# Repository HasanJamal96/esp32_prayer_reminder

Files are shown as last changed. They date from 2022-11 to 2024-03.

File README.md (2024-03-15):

# esp32_prayer_reminder
This project is a prayer reminder system built using an ESP32. It assists users in staying informed about prayer times and offers a convenient way to play surahs.

## Hardware
  - ESP32
  - MAX98357
  - 2 push button
  - 1 toggle switch
  - RTC DS3231
  - Speaker

## Working:
### Mode:
  - **Configuration Mode:**
      1. Users connect to a dedicated ESP32 access point and configure settings through a captive portal.
      2. Set RTC time and date for accurate prayer calculations.
      3. Select the user's country for relevant prayer time data.
      4. Connect ESP32 rto Wi-Fi and download prayer timings from the internet.
  - **Normal Mode:**
      1. Provides immediate access to prayer information and surah playback.
      2. Announce the current prayer time upon pressing the first push button.
      3. Play a stored surah from memory by pressing the second push button.

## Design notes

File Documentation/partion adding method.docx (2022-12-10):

Find boards.txt file

Mine is located at

C:\Users\PC\AppData\Local\Arduino15\packages\esp32\hardware\esp32\1.0.6

PC is the name of my computer.
AppData folder is hidden by default, so you have to unhide this.
1.0.6 is the version of ESP32 I am using

Open boards.txt file in text editor and find the following lines.

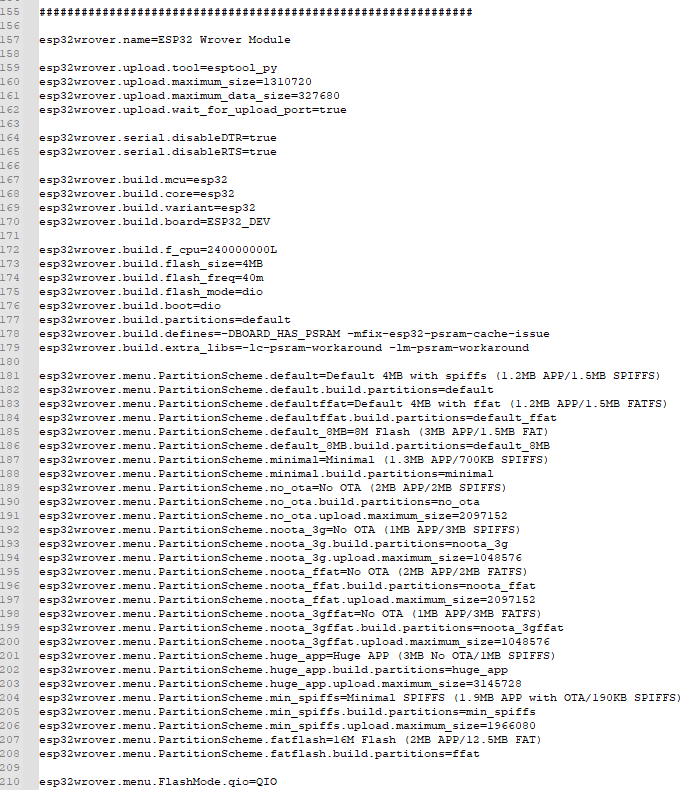
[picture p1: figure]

Add these three lines at the end

esp32wrover.menu.PartitionScheme.large_spiffs=Prayer Partition (1.25MB APP/OTA/12.5MB SPIFFS)
esp32wrover.menu.PartitionScheme.large_spiffs.build.partitions=prayer_partition
esp32wrover.menu.PartitionScheme.large_spiffs.upload.maximum_size=13107200

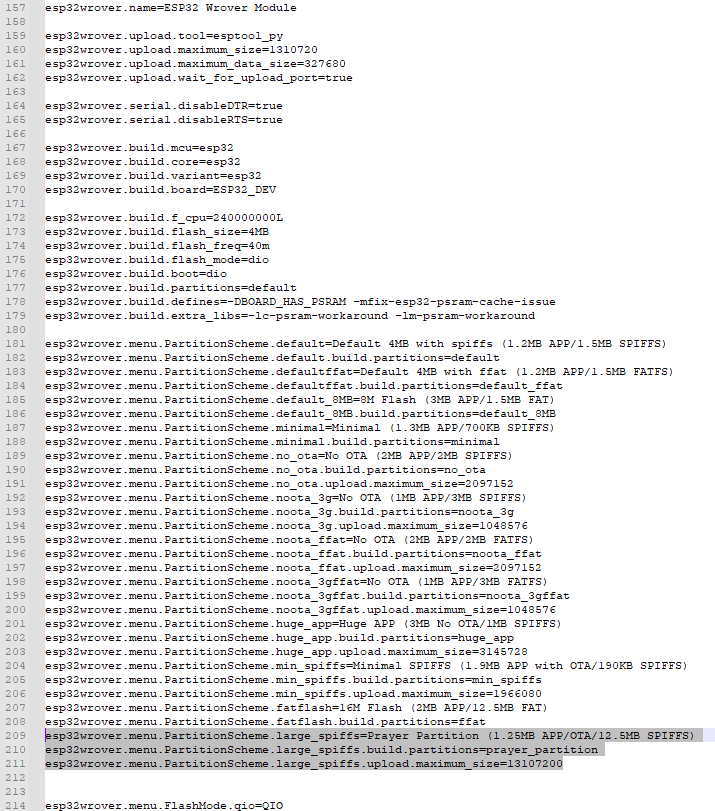
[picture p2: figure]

now go to this location and add this file prayer_partition.csv

C:\Users\PC\AppData\Local\Arduino15\packages\esp32\hardware\esp32\1.0.6\tools\partitions

Before adding

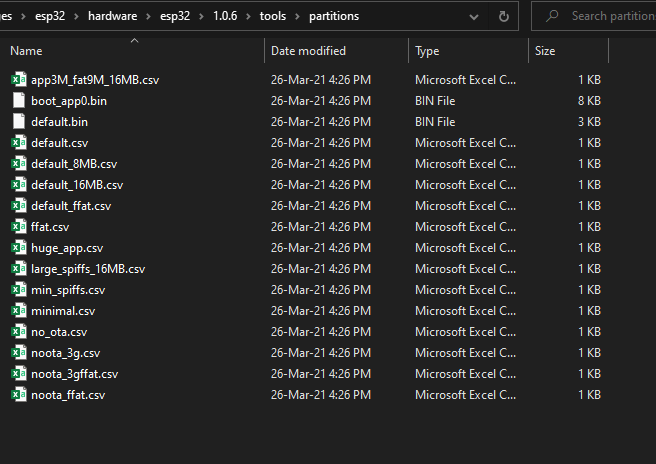
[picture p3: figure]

After adding

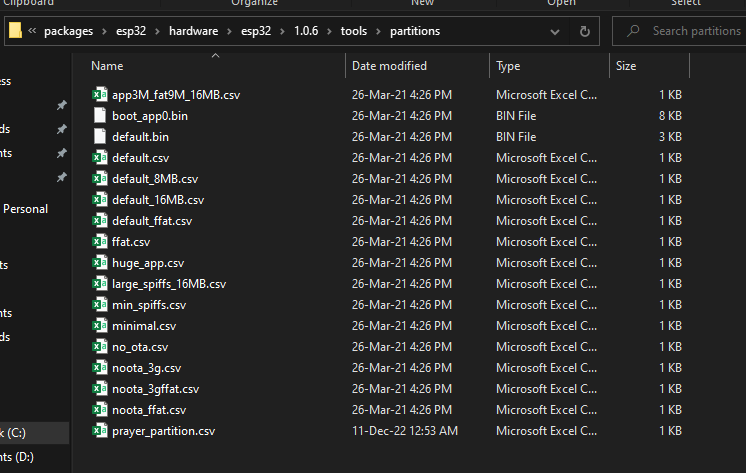
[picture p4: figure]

Restart Arduino IDE, connect ESP32 board

Now select board and partition in IDE under tools

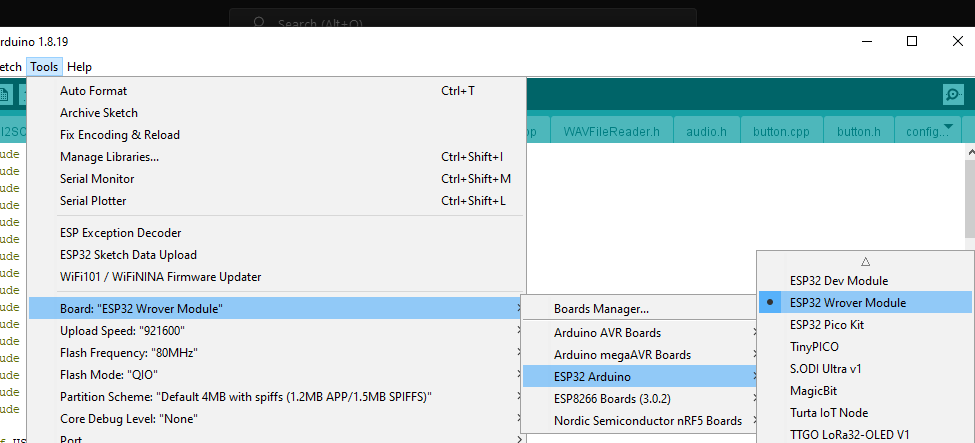
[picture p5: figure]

Select new added partition

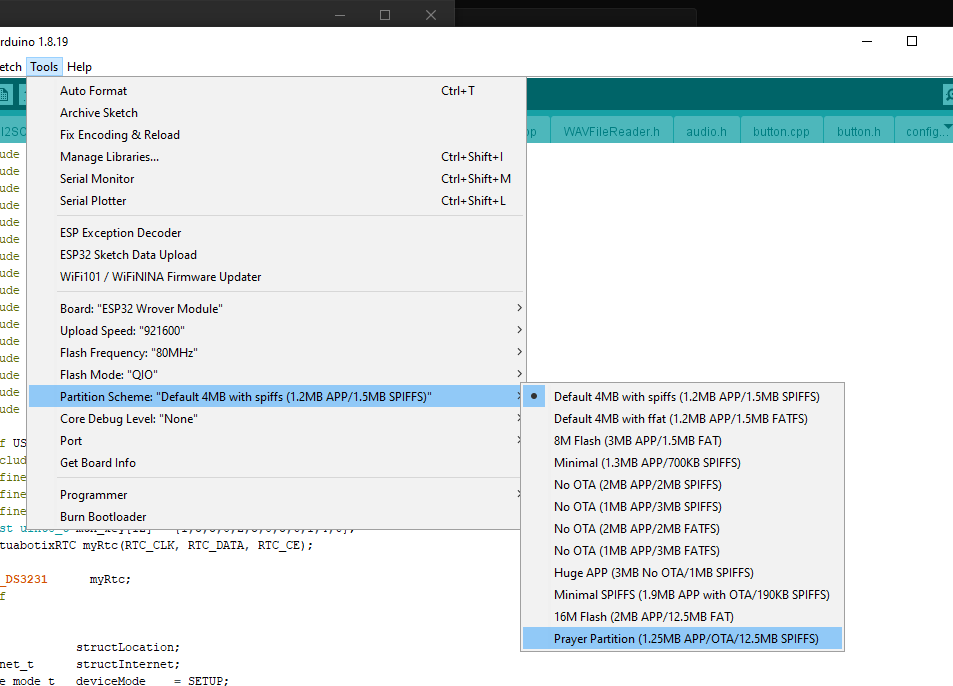
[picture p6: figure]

Upload audio and web files in ESP32

Make sure Serial monitor is close now click on ESP32 Sketch Data Upload.

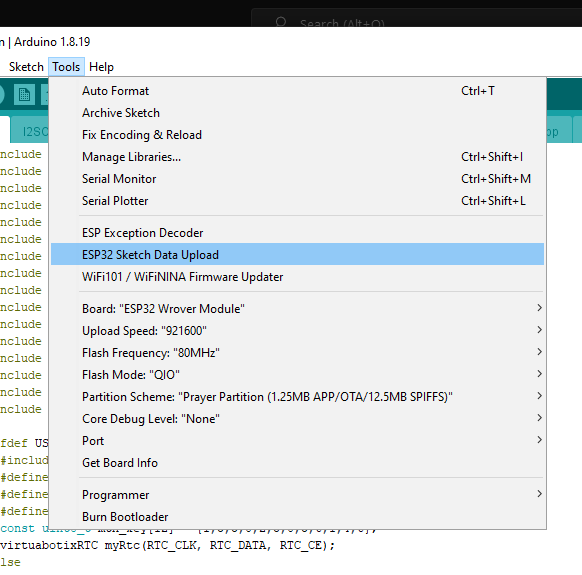
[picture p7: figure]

After successfully upload files in ESP32 now upload code in ESP32.

Click on upload button.

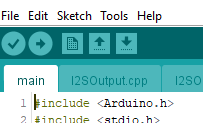
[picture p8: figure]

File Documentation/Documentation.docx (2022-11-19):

Prayer Reminder

Install Arduino IDE:

Download IDE from this link make sure to download version 1.8.19

https://www.arduino.cc/en/software

after downloading follow the installation process.

Add ESP board in Arduino IDE:

1. In Arduino IDE, go to File> Preferences

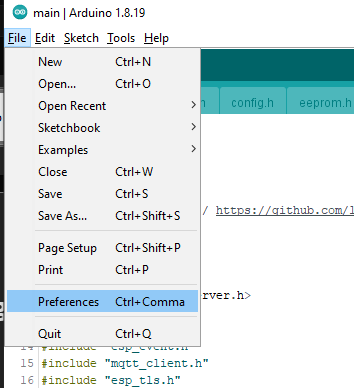
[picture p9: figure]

2. Enter the following into the Additional Board Manager URLs field and click Ok:

https://raw.githubusercontent.com/espressif/arduino-esp32/gh-pages/package_esp32_index.json

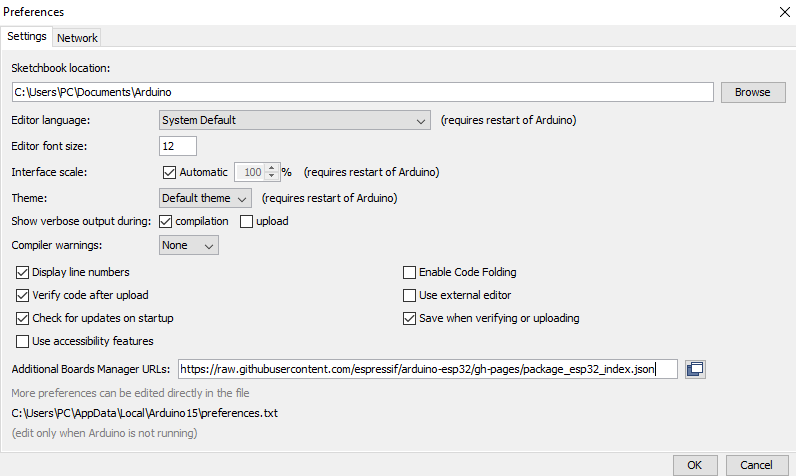
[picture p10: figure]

3. Open the Boards Manager. Go to Tools > Board > Boards Manager…

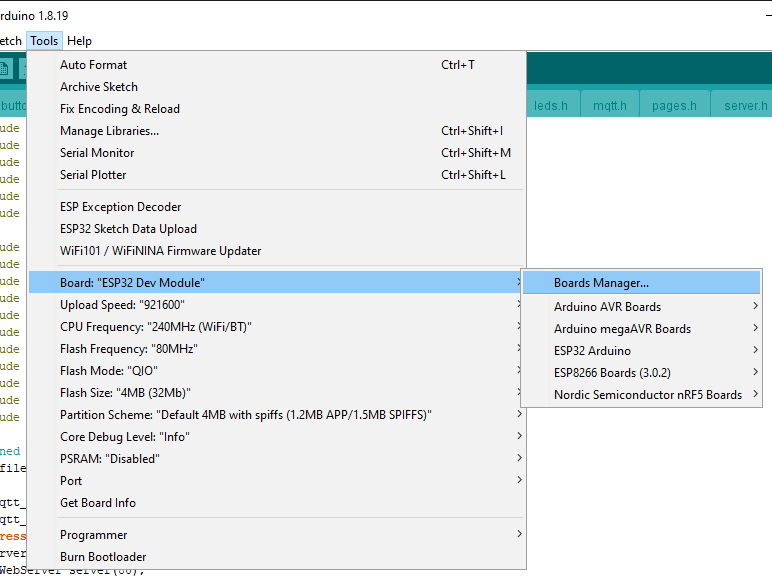
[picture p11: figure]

4. Search for ESP32, select 1.0.6 version and click install

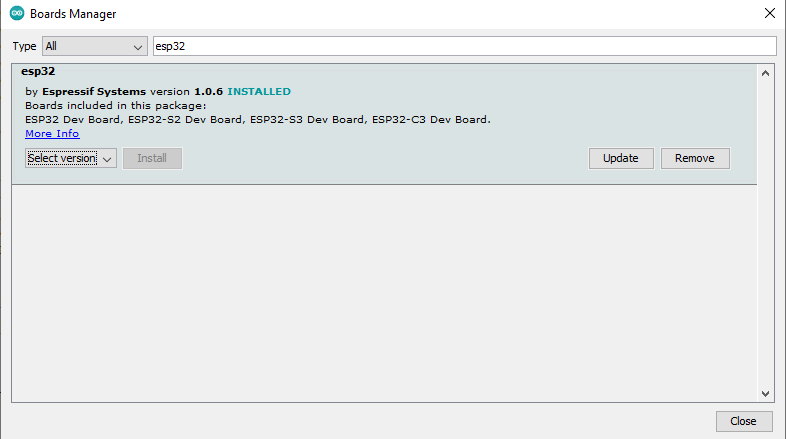
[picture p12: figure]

Install Required Libraries:

All the required libraries added with documentation have to be added in Arduino IDE.

Go to Sketch >> Include Library >> Add .ZIP Library…

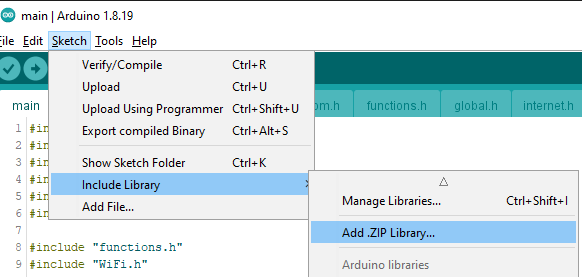
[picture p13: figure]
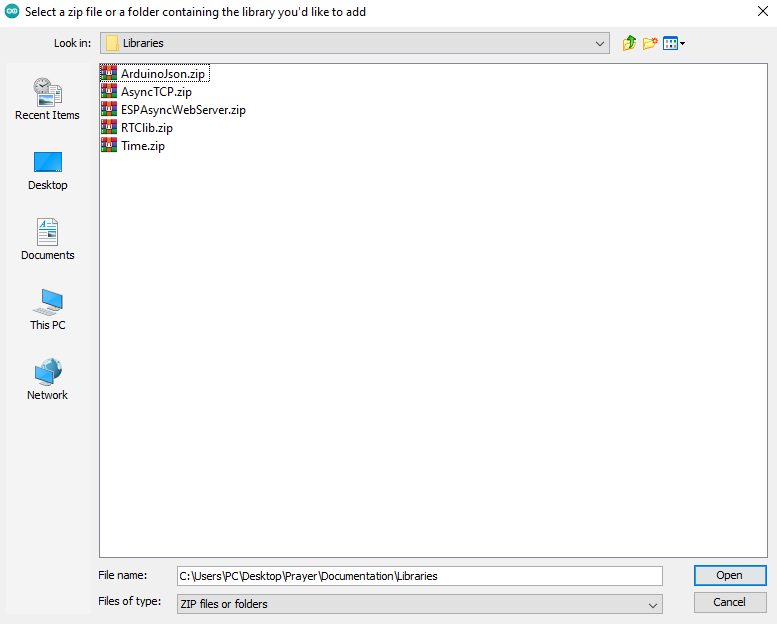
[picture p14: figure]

To the Libraries added with this documentation and select any one of the libraries.

Follow the same for others.

In config.h file you can enable/disable debugging of the code.

Uncomment these lines to enable debugging.

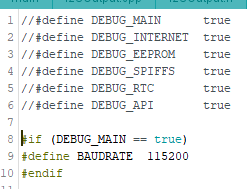
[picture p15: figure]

Debugging will be shown on Serial Monitor. Make sure in final version comment these lines to save memory and processing power of the controller.

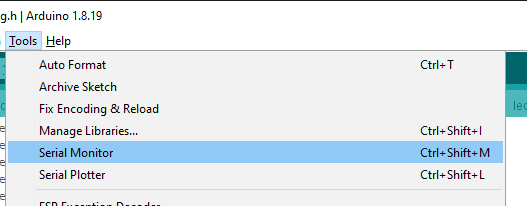
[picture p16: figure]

How to upload code in Controller

Connect controller with PC.

Select following settings in IDE.

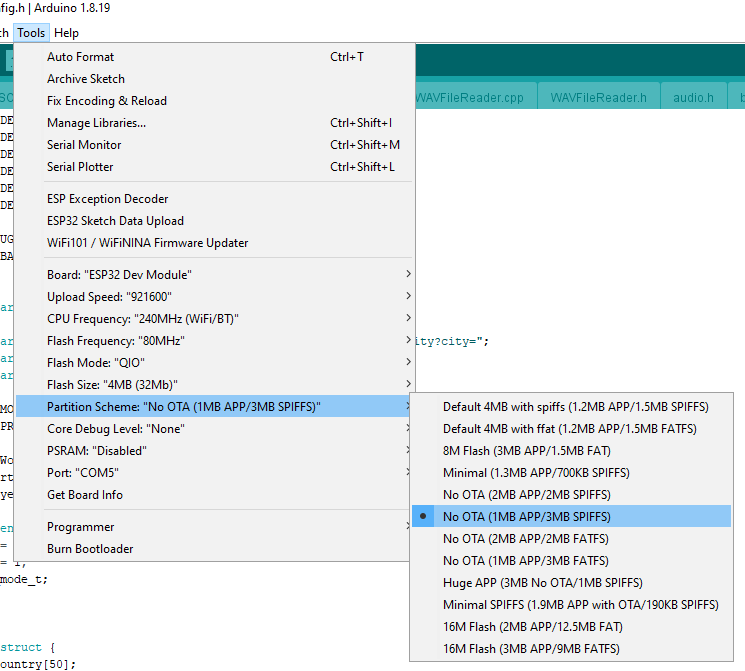
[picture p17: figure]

Port will be the COM port at which your ESP Controller is connected.

Click on upload button and code should upload in the controller after compiling.

How to upload files (Audio/Setup) in ESP Memory

1. Go to the following link and download the highlighted file

https://github.com/me-no-dev/arduino-esp32fs-plugin/releases/

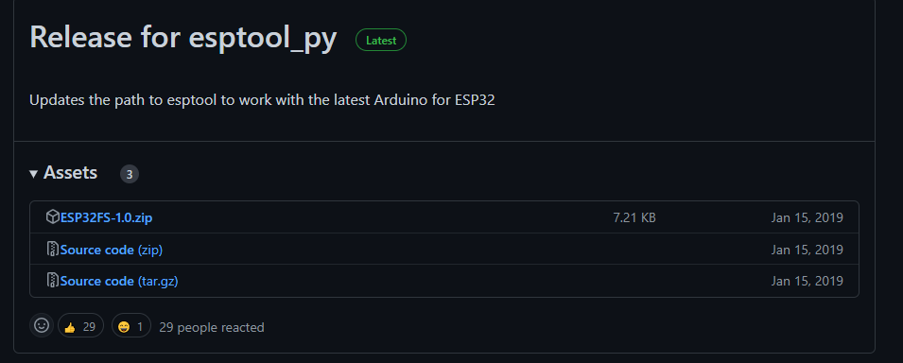
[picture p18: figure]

2. After downloading, in Arduino IDE go to Files>>Preferences. Go to Sketchbook location, yours may be different.

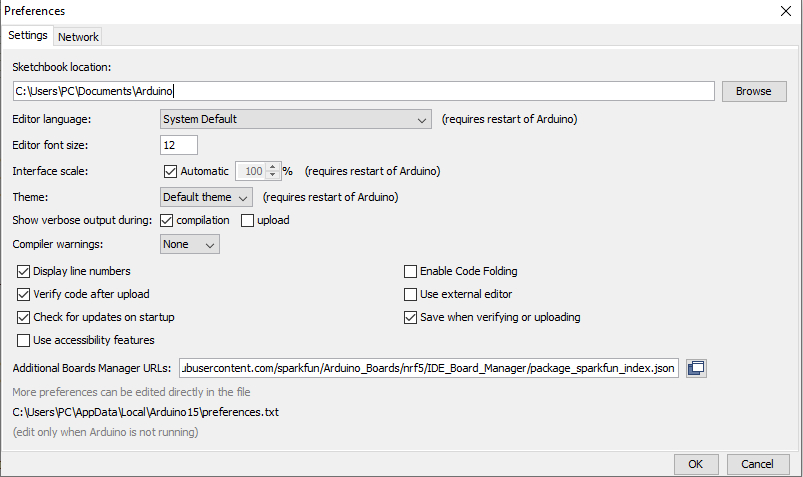
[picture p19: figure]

3. Create tools folder. And extract the files in downloaded in step 1 in tools folder.

Your directory will look like this.

Restart Arduino IDE.

To check if the plugin was successfully installed, open your Arduino IDE. Select your ESP32 board, go to Tools and check that you have the option ESP32 Sketch Data Upload.

Now click on this option it will upload the Audio and setup files in ESP.

While uploading these files make sure your serial monitor is not running.

Circuit Diagram

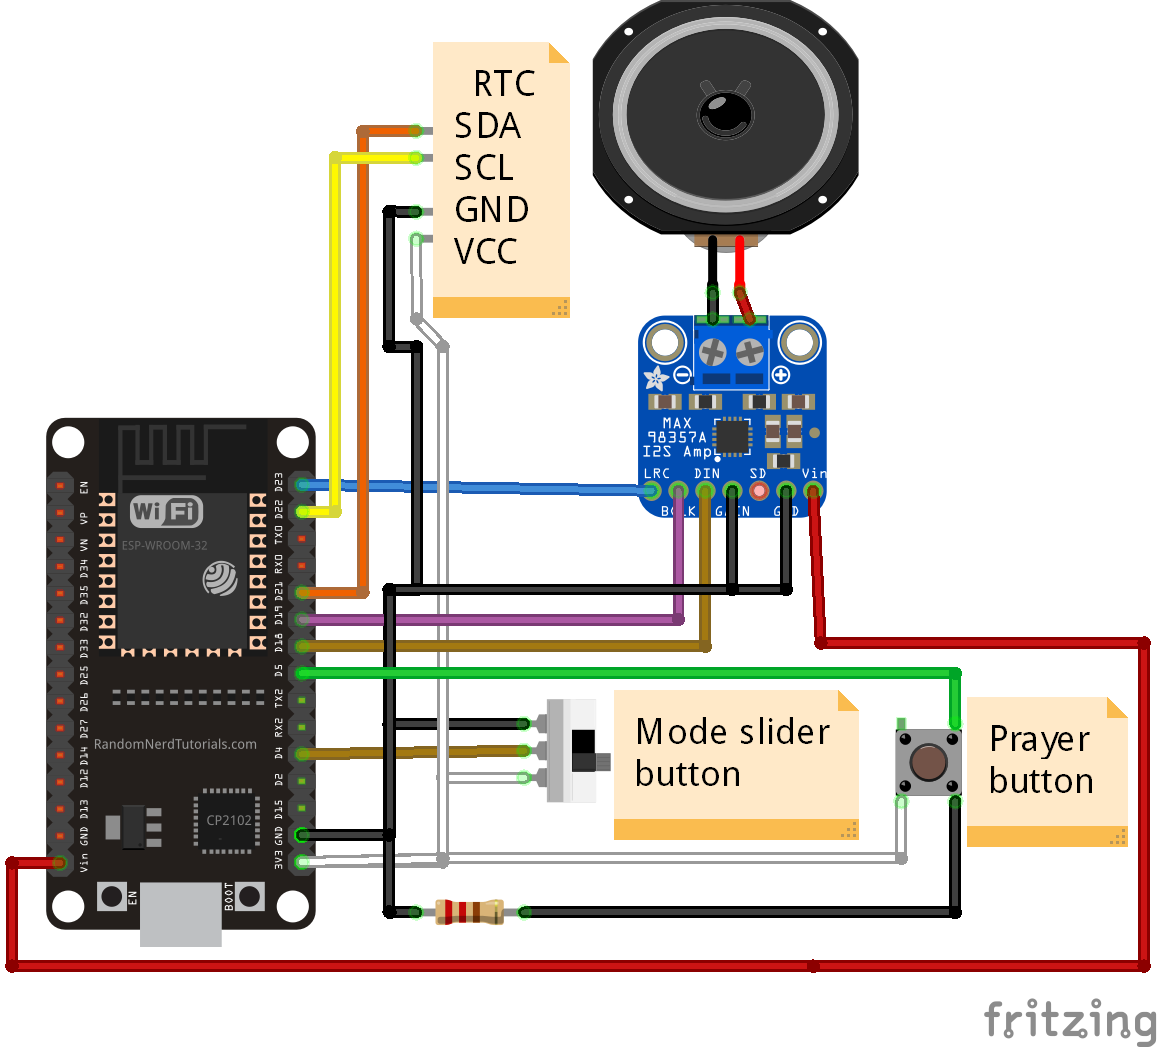
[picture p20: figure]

Device has two modes

1. Setup mode
2. Watch mode

Slider mode button will select the mode of the device.

If the slider is towards black wire side device will be in Watch mode.

If the slider is towards white wire side device will be in Setup mode.

In setup mode device will create its hotspot and user will connect to it using his mobile.

After connected to device’s hotspot webpage will open where user can set country, city, time of the device and Wi-Fi. In order to download the prayer time user first connect the device to stable Wi-Fi connection from Wi-Fi settings page. Then user should set Time of the device if needed and then user should select country and city than start the download process, download progress will be shown in country settings page. Prayer data will depend on current year and location selected by user. So, if user changes his location or next year has been started, user has to download the data again. once data is downloaded user will not require Wi-Fi connection.

In Watch mode whenever user presses Prayer button device will tell the Prayer time, provided that user first downloaded the data.

Note:

If you do not have the slide button Just connect the D4 pin on ESP32 to GND pin of ESP32 to start the Setup mode

Or connect D4 to pin of ESP32 to 3.3V of ESP32 to start the Watch mode.

Make sure D4 is connected to either GND or 3.3v if it connected to both of them then ESP may get damage.

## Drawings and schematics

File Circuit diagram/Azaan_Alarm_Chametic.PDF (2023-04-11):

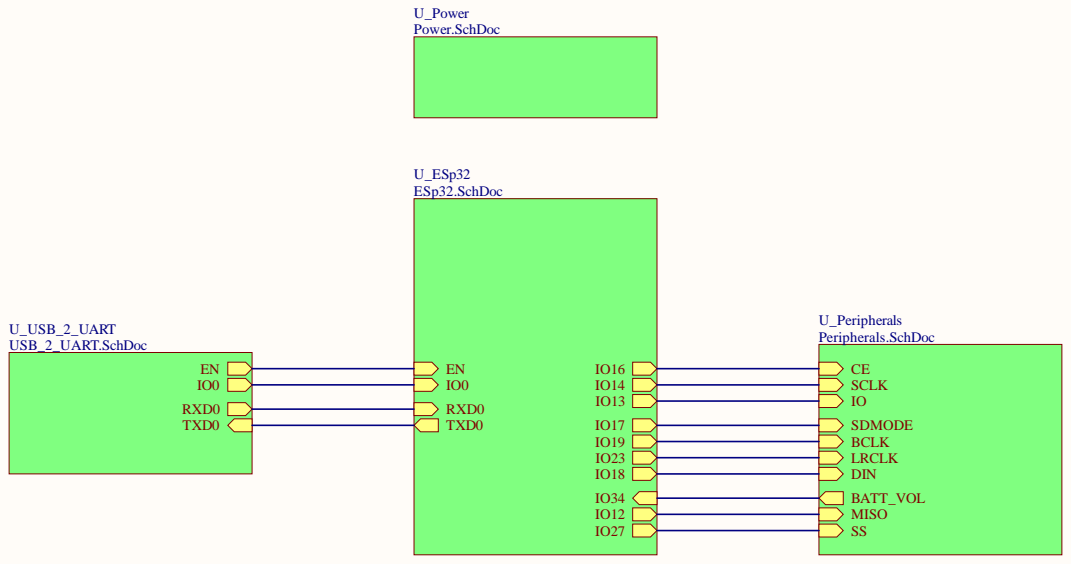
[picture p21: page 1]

Title Top Level

Size: A4 | Company: barkiEngineering | Revision:
Date: 26/11/2022 Time: 5:39:42 PM | Sheet 1 of 5

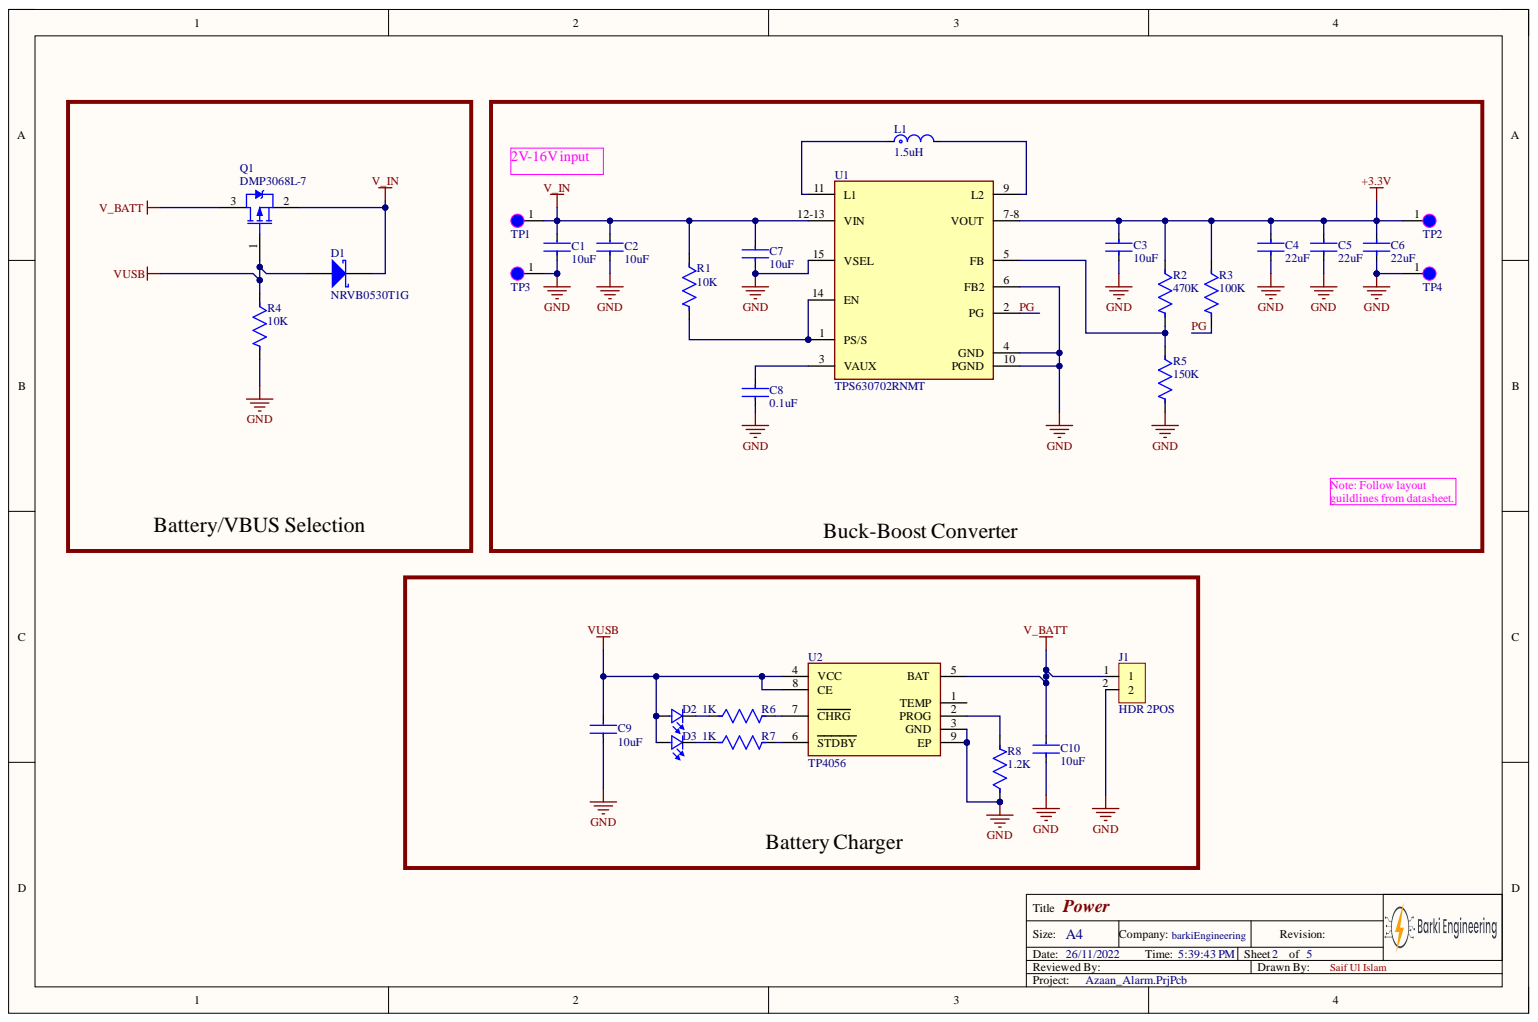
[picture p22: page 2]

Title Power

Size: A4 | Company: barkiEngineering | Revision:
Date: 26/11/2022 Time: 5:39:43 PM | Sheet 2 of 5

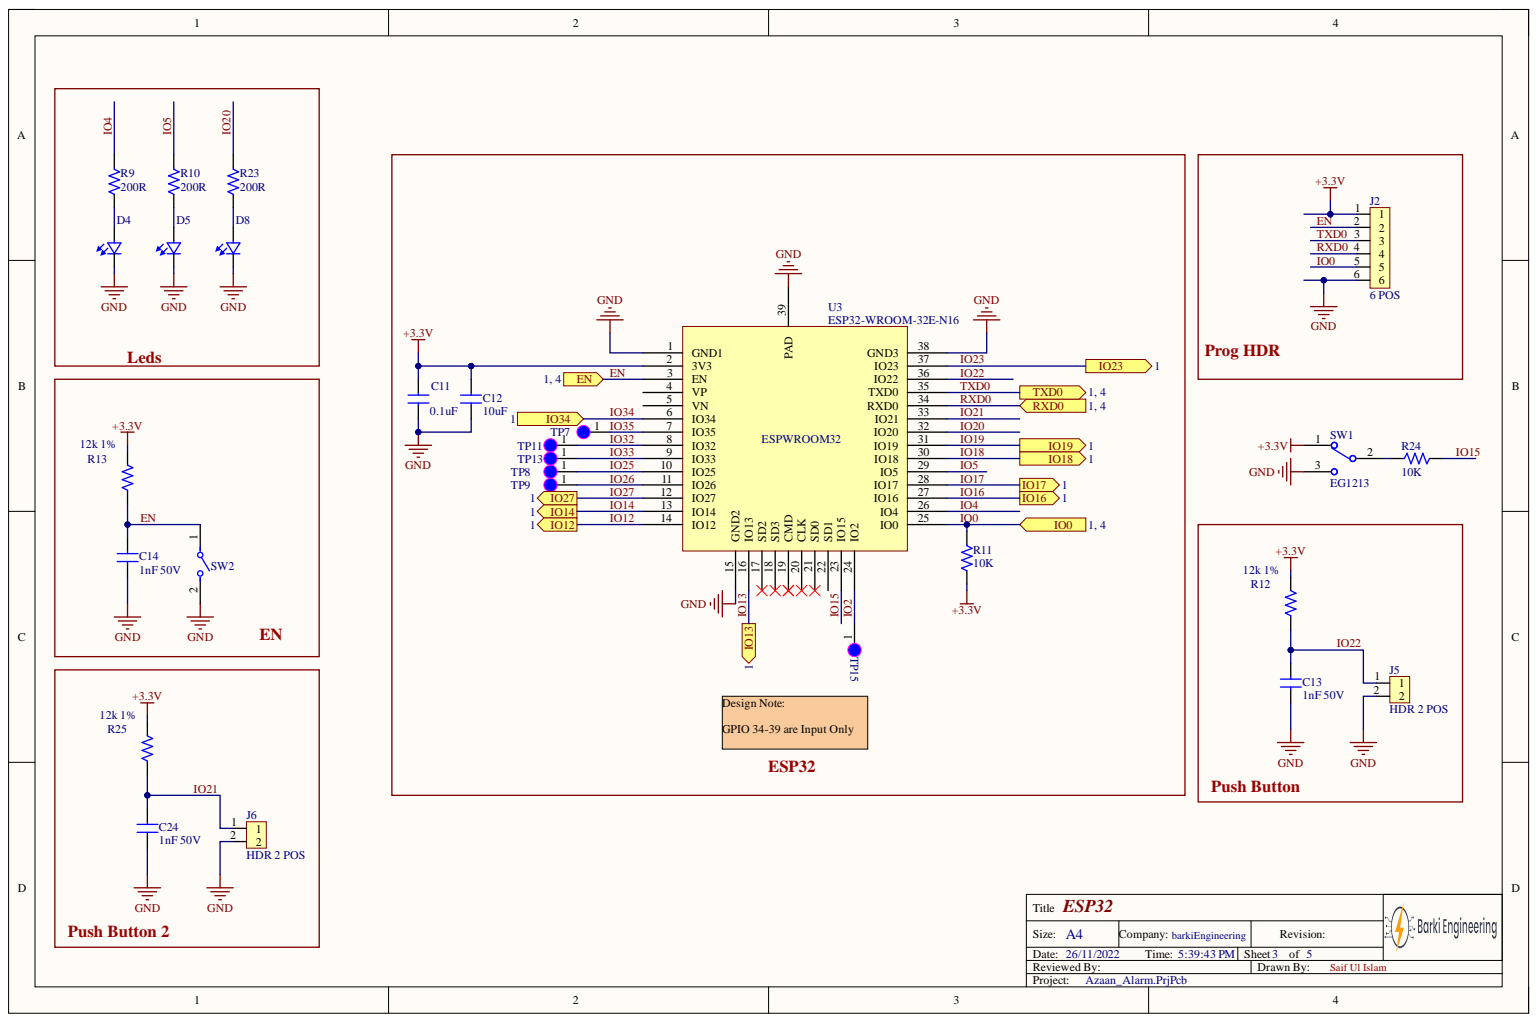
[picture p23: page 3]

Size : A 4 | Compan y : barki Engine ering | Rev i s i o n :
Dat e : 2 6 / 1 1 / 2 0 2 2 T ime : 5 : 3 9 : 4 3 PM | Shee t 3 o f 5

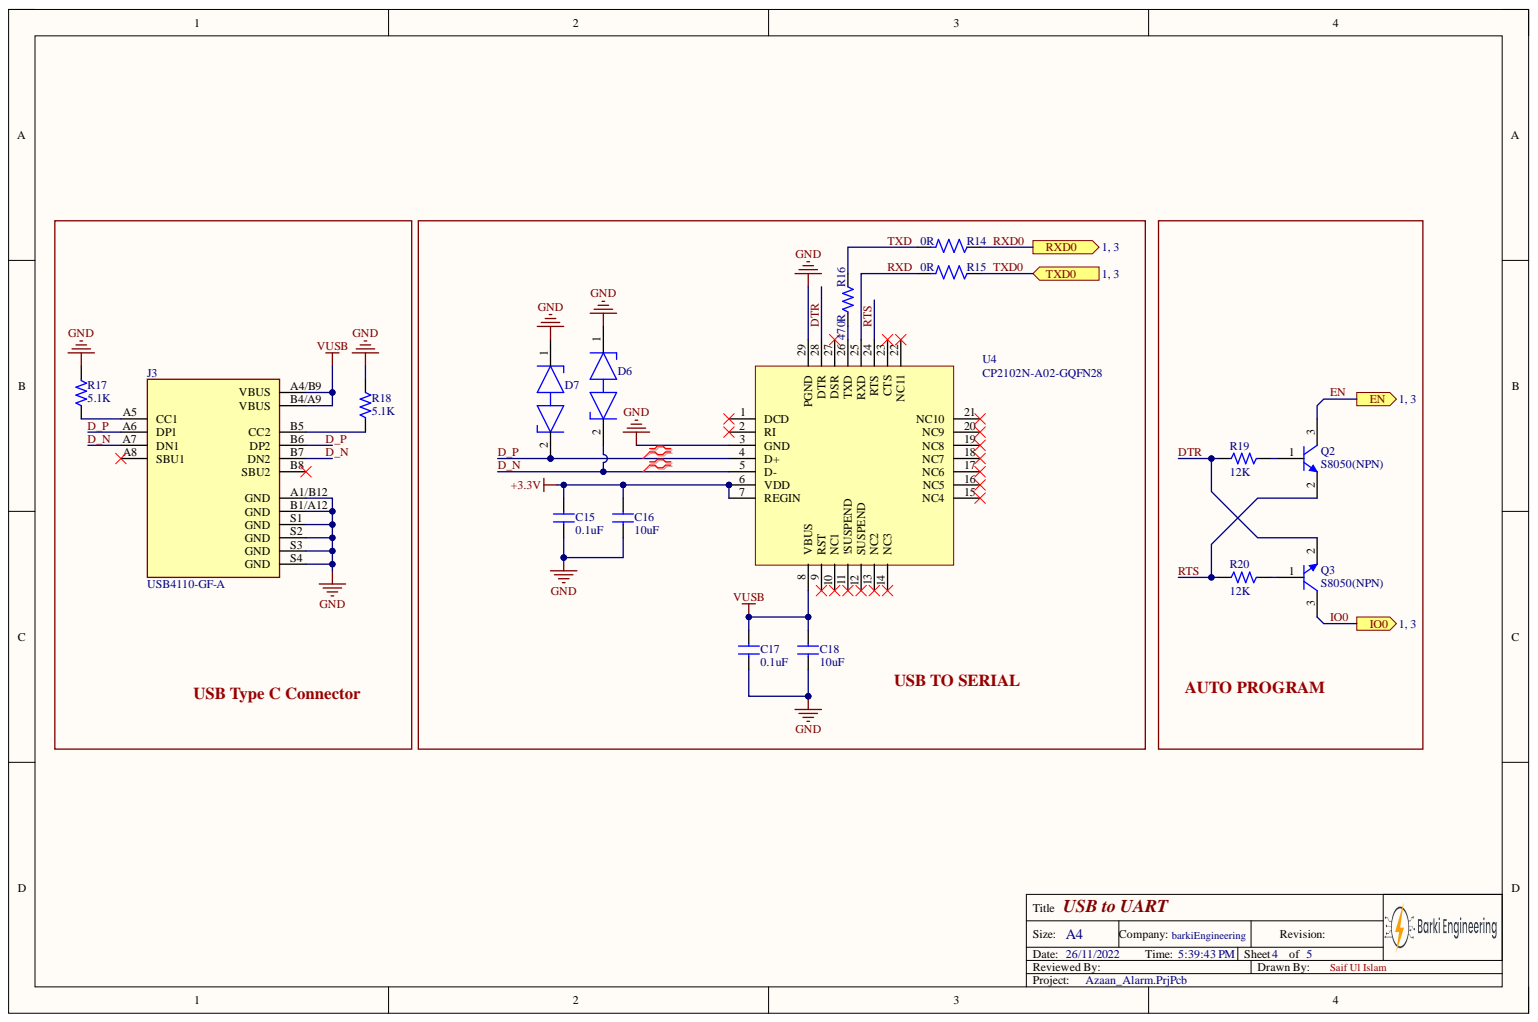
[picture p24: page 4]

NC11 22 CTS 23 RTS 24 RXD 25 TXD 26 DSR 27 DTR 28 PGND 29

T i tl e USB to UART

Size : A 4 | Compan y : barki Engine ering | Rev i s i o n :
Dat e : 2 6 / 1 1 / 2 0 2 2 T ime : 5 : 3 9 : 4 3 PM | Shee t 4 o f 5

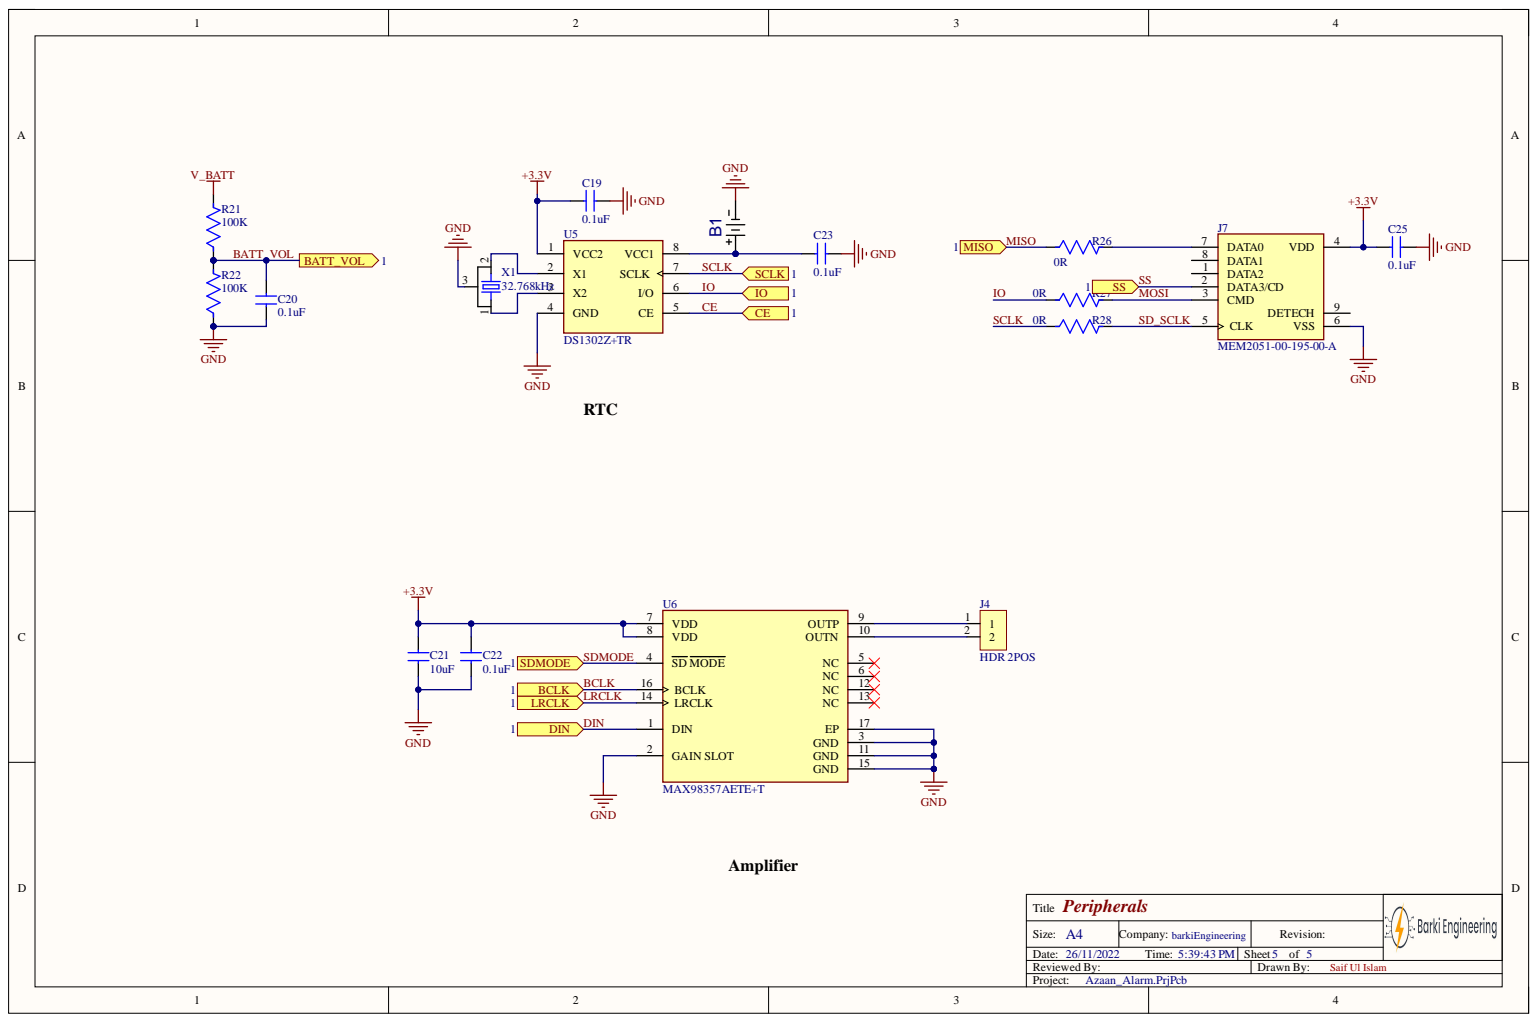
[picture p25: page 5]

Title Peripherals

Size: A4 | Company: barkiEngineering | Revision:
Date: 26/11/2022 Time: 5:39:43 PM | Sheet 5 of 5

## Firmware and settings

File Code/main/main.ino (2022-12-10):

#include <Arduino.h>
#include <stdio.h>
#include <FreeRTOS.h>
#include <driver/i2s.h>
#include "config.h"
#include "RTClib.h"
#include <EEPROM.h>
#include <DNSServer.h>
#include "WiFi.h"
#include <ESPAsyncWebServer.h>
#include "SPIFFS.h"
#include "I2SOutput.h"
#include "WAVFileReader.h"
#include "TimeLib.h"
#include <HTTPClient.h>
#include <ArduinoJson.h>

#ifdef USING_PCB
  #include <virtuabotixRTC.h>
  #define RTC_CLK   22
  #define RTC_DATA  21
  #define RTC_CE    15
  const uint8_t mth_key[12] = {1,3,3,0,2,5,0,3,6,1,4,6};
  virtuabotixRTC myRtc(RTC_CLK, RTC_DATA, RTC_CE);
#else
  RTC_DS3231      myRtc;
#endif


loc_t           structLocation;
internet_t      structInternet;
device_mode_t   deviceMode    = SETUP;
server_status_t structServer  = STOPPED;

voltage_status_t    currentVoltageStatus = LOW_VOLTAGE;
voltage_status_t    lastVoltageStatus = LOW_VOLTAGE;
unsigned long lastVoltageRead = 0;

IPAddress        apIP(8,8,8,8);
DNSServer        dnsServer;
AsyncWebServer   server(80);
AsyncEventSource events("/events");

DynamicJsonDocument doc(60000);

void serverRoutes();
void startServer();

unsigned long currentUnixTime;
int currentYear          = 1970;
int currentSelectedMonth = 0;
int currentSelectedDay = 0;
int lastSelectedMonth = 0;
int lastSelectedDay = 0;
int currentHour = 0;
int currentMinute = 0;
char currentPrayerTime[6];

unsigned long lastRTCUpdate = 0;
tmElements_t my_time;
#include "memory.h"
#include "getData.h"
#include "internet.h"
#include "eeprom.h"
#include "rtc.h"
#include "server.h"
#include "button.h"
#include "audio.h"

Button  buttonMode(MODE_BUTTON, 500);
Button  buttonPrayer(PRAYER_BUTTON, 500);
Button  buttonExtra(EXTRA_BUTTON, 500);

#define SD_MODE_PIN 17
i2s_pin_config_t i2s_speaker_pins = {
  .bck_io_num = GPIO_NUM_27,  // BCLK
  .ws_io_num = GPIO_NUM_14,   // LRCL
  .data_out_num = GPIO_NUM_26,// DIN
  .data_in_num = I2S_PIN_NO_CHANGE
};



unsigned long convertStringToUnix(String string, bool nextDay) {
  int h, m;
  unsigned long ut;
  h = string.substring(0,2).toInt();
  m = string.substring(3,5).toInt();
  my_time.Second = 0;
  my_time.Hour   = h;
  my_time.Minute = m;
  my_time.Day    = currentSelectedDay;
  my_time.Month  = currentSelectedMonth;
  my_time.Year   = currentYear - 1970;
  ut = makeTime(my_time);
  if(h == 0 && nextDay) {
    ut += (24*60*60);
  }
  return ut;
}


void play_task(void *param) {
  Output *output = new I2SOutput(I2S_NUM_0, i2s_speaker_pins);
  unsigned long prayersUnixTime[5];
  while (true){
    if(buttonPrayerPressed) {
      buttonPrayerPressed = false;
      if(prayerDataAvailable) {
        String p = String(currentSelectedDay);
        unsigned long sunRiseUnix  = convertStringToUnix(doc[p][5], false);
        unsigned long sunSetUnix   = convertStringToUnix(doc[p][6], false);
        unsigned long midNightUnix = convertStringToUnix(doc[p][7], true);
        /*Serial.print("Current Unix: ");
        Serial.println(currentUnixTime);
        Serial.print(" sunset Unix: ");
        Serial.print(sunSetUnix);
        Serial.print(" sunrise Unix: ");
        Serial.println(sunRiseUnix);*/
        for(uint8_t i=0; i<5; i++)
          prayersUnixTime[i] = convertStringToUnix(doc[p][i], false);

        bool prayerFound = false;
        for(uint8_t i=0; i<5; i++) {
          /*Serial.print("Current Unix: ");
          Serial.print(currentUnixTime);
          Serial.print(" Prayer Unix: ");
          Serial.println(prayersUnixTime[i]);*/
          
          switch(i) {
            case 0:
              if(currentUnixTime >= prayersUnixTime[i] && currentUnixTime < sunRiseUnix) {
                #if (DEBUG_MAIN == true)
                  Serial.println("[Prayer] Fajr");
                #endif
                playingAudio = true;
                play(output, "/spiffs/Fajr.wav");
                prayerFound = true;
              }
              break;
            case 1:
              if(currentUnixTime >= prayersUnixTime[i] && currentUnixTime < (prayersUnixTime[i+1] - (20*60*1000))) {
                #if (DEBUG_MAIN == true)
                  Serial.println("[Prayer] Duhr");
                #endif
                playingAudio = true;
                play(output, "/spiffs/Duhr.wav");
                prayerFound = true;
              }
              break;
            case 2:
              if(currentUnixTime >= prayersUnixTime[i] && currentUnixTime < sunSetUnix) {
                #if (DEBUG_MAIN == true)
                  Serial.println("[Prayer] Asr");
                #endif
                playingAudio = true;
                play(output, "/spiffs/Asr.wav");
                prayerFound = true;
              }
              break;
            case 3:
              if(currentUnixTime >= prayersUnixTime[i] && currentUnixTime < (prayersUnixTime[i+1] - (10*60*1000))) {
                #if (DEBUG_MAIN == true)
                  Serial.println("[Prayer] Maghrib");
                #endif
                play(output, "/spiffs/Maghrib.wav");
                playingAudio = true;
                prayerFound = true;
              }
              break;
            case 4:
              if(currentUnixTime >= prayersUnixTime[i] && currentUnixTime < midNightUnix) {
                #if (DEBUG_MAIN == true)
                  Serial.println("[Prayer] Isha");
                #endif
                playingAudio = true;
                play(output, "/spiffs/Isha.wav");
                prayerFound = true;
              }
              break;
          }
        }
        if(!prayerFound) {
          #if (DEBUG_MAIN == true)
            Serial.println("[Prayer] No Prayer time");
          #endif
          playingAudio = true;
          play(output, "/spiffs/NoPrayer.wav");
        }
      }
    }
    else if(buttonExtraPressed) {
      buttonExtraPressed = false;
      currentAudioFileIndex += 1;
      if(currentAudioFileIndex >= TOTAL_FILES) {
        currentAudioFileIndex = 0;
      }
      playingAudio = true;
      play(output, fileNamesList[currentAudioFileIndex]);
    }
    vTaskDelay(pdMS_TO_TICKS(1000));
  }
}


void setup() {
  #if (DEBUG_MAIN == true)
    Serial.begin(BAUDRATE);
    Serial.printf("[Main] Setup start\n");
    Serial.printf("[Main] Prayer reminder\n");
    Serial.printf("[Main] Version: ");
    Serial.println(VERSION);
  #endif

  initEEPROM();
  readonfigurations();
  beginRTC();

  buttonPrayer.begin();
  buttonMode.begin();
  buttonExtra.begin();

  pinMode(STATUS_LED, OUTPUT);
  pinMode(BATTERY_HIGH_LED, OUTPUT);
  pinMode(BATTERY_LOW_LED, OUTPUT);
  pinMode(BATTERY_MEASURE_PIN, INPUT);
  pinMode(SD_MODE_PIN, OUTPUT);
  digitalWrite(SD_MODE_PIN, HIGH); // HIGH Right channel, LOW AMP will shutdown(No Audio)
  
  delay(1000);

  if(buttonMode.read())
    deviceMode = SETUP;
  else
    deviceMode = WATCH;
  
  mountSPIFFS();

  if(deviceMode == SETUP) {
    #if (DEBUG_MAIN == true)
      Serial.printf("[Main] Device is in setup mode\n");
    #endif
    digitalWrite(STATUS_LED, HIGH);
    initInternet();
    delay(200);
    startServer();
  }
  
  if(deviceMode == WATCH) {
    #if (DEBUG_MAIN == true)
      Serial.printf("[Main] Device is in watch mode\n");
      Serial.printf("[Main] Device must have prayer data stored and RTC configured\n");
    #endif
    digitalWrite(STATUS_LED, LOW);
    updateRTC();
    currentSelectedMonth = lastSelectedMonth;
    currentSelectedDay   = lastSelectedDay;
    updatePrayerData();
    xTaskCreate(play_task, "PLAYTASK", 4096, NULL, 0, NULL);
  }
  
  #if (DEBUG_MAIN == true)
    Serial.printf("[Main] Setup complete\n");
  #endif
}

void restartESP() {
  #if (DEBUG_MAIN == true)
    Serial.printf("[Main] Restarting in \n");
  #endif
  for(int8_t i=3; i>=0; i--) {
    #if (DEBUG_MAIN == true)
      Serial.printf("%d\n", i);
    #endif
    vTaskDelay(1000);
  }
  ESP.restart();
}

float getCurrentVoltage() {
  float rawValue = analogRead(BATTERY_MEASURE_PIN);
  rawValue = (rawValue * 3.3) / 4095;
  return rawValue / (RESISTOR_2/(RESISTOR_1+RESISTOR_2)); 
}


void loop() {
  if(buttonMode.read() && deviceMode == WATCH)
    restartESP();
  else if(!buttonMode.read() && deviceMode == SETUP)
    restartESP();
    
  if(deviceMode == SETUP) {
    internetHandle();
    if(structServer == RUNNING)
      dnsServer.processNextRequest();

    if(startDownload) {
      getDataFromAPI();
      startDownload = false;
    }
  }
  else {
    if(millis() - lastRTCUpdate >= 5000 && (!playingAudio)) {
      updateRTC();
      if(lastSelectedMonth != currentSelectedMonth) {
        currentSelectedMonth = lastSelectedMonth;
        updatePrayerData();
      }
    }
    buttonPrayer.read();
    buttonExtra.read();
    if(buttonPrayer.pressedFor(300)) {
      if(playingAudio) {
        playingAudio = false;
        vTaskDelay(500);
      }
      buttonPrayerPressed = true;
    }
    else if(buttonExtra.pressedFor(300)) {
      if(playingAudio) {
        playingAudio = false;
        vTaskDelay(500);
      }
      buttonExtraPressed = true;
    }
  }
  if(millis() - lastVoltageRead >= 10000 && (!playingAudio)) {
    if(getCurrentVoltage() >= FULL_THRESHOLD_VOLTAGE) {
      currentVoltageStatus = FULL_VOLTAGE;
    }
    else if(getCurrentVoltage() < FULL_THRESHOLD_VOLTAGE && getCurrentVoltage() > LOW_THRESHOLD_VOLTAGE) {
      currentVoltageStatus = MID_VOLTAGE;
    }
    else if(getCurrentVoltage() <= LOW_THRESHOLD_VOLTAGE) {
      currentVoltageStatus = LOW_VOLTAGE;
    }
    if(currentVoltageStatus != lastVoltageStatus) {
      if(currentVoltageStatus == LOW_VOLTAGE) {
        digitalWrite(BATTERY_LOW_LED, HIGH);
        digitalWrite(BATTERY_HIGH_LED, LOW);
      }
      else if(currentVoltageStatus == MID_VOLTAGE) {
        digitalWrite(BATTERY_LOW_LED, LOW);
        digitalWrite(BATTERY_LOW_LED, LOW);
        
      }
      else if(currentVoltageStatus == FULL_VOLTAGE) {
        digitalWrite(BATTERY_LOW_LED, LOW);
        digitalWrite(BATTERY_HIGH_LED, HIGH);
      }
      lastVoltageStatus = currentVoltageStatus;
    }
    lastVoltageRead = millis();
  }
}

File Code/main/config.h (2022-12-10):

//#define DEBUG_MAIN      true
//#define DEBUG_INTERNET  true
//#define DEBUG_EEPROM    true
//#define DEBUG_SPIFFS    true
//#define DEBUG_RTC       true
//#define DEBUG_API       true

#define USING_PCB //uncomment this line if you are using RTC DS1302


#if (DEBUG_MAIN == true)
#define BAUDRATE  115200
#endif

const char VERSION[] = "0.2";

const char* BASE_API_START = "http://api.aladhan.com/v1/calendarByCity?city=";
const char* BASE_API_MID = "&country=";
const char* BASE_API_END = "&month=";

#define MODE_BUTTON   39
#define PRAYER_BUTTON 36
#define EXTRA_BUTTON  35

#define BATTERY_MEASURE_PIN 34
const float FULL_THRESHOLD_VOLTAGE = 1.80;
const float LOW_THRESHOLD_VOLTAGE = 1.6;
const float RESISTOR_1 = 100000;
const float RESISTOR_2 = 100000;

#define STATUS_LED          2
#define BATTERY_HIGH_LED    4
#define BATTERY_LOW_LED     16

typedef enum: uint8_t {
  LOW_VOLTAGE =  0,
  FULL_VOLTAGE = 1,
  MID_VOLTAGE  = 2,
}voltage_status_t;

bool rtcWorking = false;
bool startDownload = false;
bool prayerDataAvailable = false;
bool playingAudio = false;

bool buttonPrayerPressed = false;
bool buttonExtraPressed = false;

const uint8_t TOTAL_FILES     = 3;
int8_t currentAudioFileIndex = -1;
const char *fileNamesList[TOTAL_FILES] = {"/spiffs/Salam.wav", "/spiffs/Al-Fatihah.wav", "/spiffs/Ayat Al-Kursi.wav"};
//const char *fileNamesList[TOTAL_FILES] = {"/spiffs/Salam.wav", "/spiffs/Maghrib.wav", "/spiffs/Fajr.wav"};

typedef enum: uint8_t {
  SETUP = 0,
  WATCH = 1,
}device_mode_t;



typedef struct {
  char country[50];
  char city[50];
}loc_t;


typedef enum: uint8_t {
  RUNNING = 0,
  STOPPED = 1,
}server_status_t;


typedef enum: uint8_t {
  CONNECTING   = 0,
  CONNECTED    = 1,
  DISCONNECTED = 2,
}internet_status_t;

typedef struct {
  char wifiName[30] = "";
  char wifiPass[30] = "";
  char apName[30]   = "Prayer Hotspot ";
  char apPass[10]   = "123456789";

  uint8_t disconnectReasonId = 0;
  String  scanResult = "";
  internet_status_t state;
  bool stopConnecting  = false;
  bool reconnect       = true;
  char macAddress[20];
  unsigned long  lastConnectionTry;
  const uint16_t RETRY_AFTER = 20000;
}internet_t;


const int     EEPROM_SIZE  = 1024;
const uint8_t MAGIC_NUMBER = 100;


// EEPROM Locations
const int EEPROM_MAGIC_NUMBER   = 0;
const int EEPROM_WIFI_NAME      = 1;
const int EEPROM_WIFI_PASS      = EEPROM_WIFI_NAME + 30;
const int EEPROM_COUNTRY        = EEPROM_WIFI_PASS + 30;
const int EEPROM_CITY           = EEPROM_COUNTRY   + 50;
const int EEPROM_DEVICE_STATE   = EEPROM_CITY      + 50;



// Audio File names
const char *FAJR = "Fajr.wav";
const char *DHUR = "Dhur.wav";
const char *ASR = "Asr.wav";
const char *MAGHRIB = "Maghrib.wav";
const char *ISHA = "Isha.wav";
const char *NO_PRAYER = "NoPrayer.wav";

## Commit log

2022-12-10 added some features
    [prayer_partition.csv]
2023-04-11 added schematic
